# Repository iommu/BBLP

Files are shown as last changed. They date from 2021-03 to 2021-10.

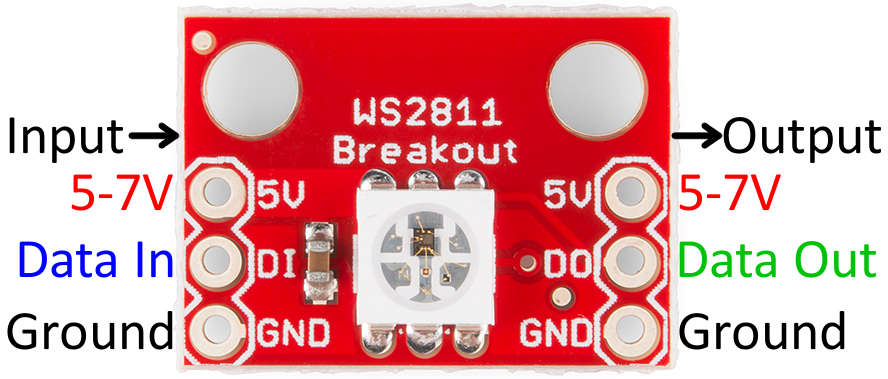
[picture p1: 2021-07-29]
Design/references/ws2812.png

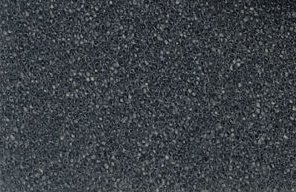
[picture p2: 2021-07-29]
Design/references/foam.jpg

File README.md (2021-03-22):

# BBLP
BreadBoard-Less Prototyper
A breadbord-less portable ECTE233 examination kit

Design files for a hardware examination kit and the associated programmer board.

## Directories
Schematics : *directory containing all schematics for the PCBs*
    - MainBoard : *schematics for the main PCB upon which everything sits*
    - IOBoard : *schematics for the small OLED I/O boards, 7 of which are mounted on the MainBoard*
    - TileBoard : *Small programmable tiles which form a stand-in for logic ICs*
    - Programmer : *A dual purpose programmer PCB with connection to the J-Link programmer, an onboard USB-TTL and a pogo pin programmer cable*
Software : *directory of all software related to the board*
    -
Design : *all design files including .stl files for 3D printing*
    -

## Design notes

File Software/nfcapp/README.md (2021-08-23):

# nfcapp

A new Flutter project.

## Getting Started

This project is a starting point for a Flutter application.

A few resources to get you started if this is your first Flutter project:

- [Lab: Write your first Flutter app](https://flutter.dev/docs/get-started/codelab)
- [Cookbook: Useful Flutter samples](https://flutter.dev/docs/cookbook)

For help getting started with Flutter, view our
[online documentation](https://flutter.dev/docs), which offers tutorials,
samples, guidance on mobile development, and a full API reference.

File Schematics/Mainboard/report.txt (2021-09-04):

Info: Front (top side) placement file: '/home/iommu/Desktop/ECTE457/BBLP/Schematics/Mainboard/output/Mainboard-top-pos.csv'.
Info: Component count: 38.
Info: Back (bottom side) placement file: '/home/iommu/Desktop/ECTE457/BBLP/Schematics/Mainboard/output/Mainboard-bottom-pos.csv'.
Info: Component count: 63.
Info: Full component count: 101.
Info: File generation successful.

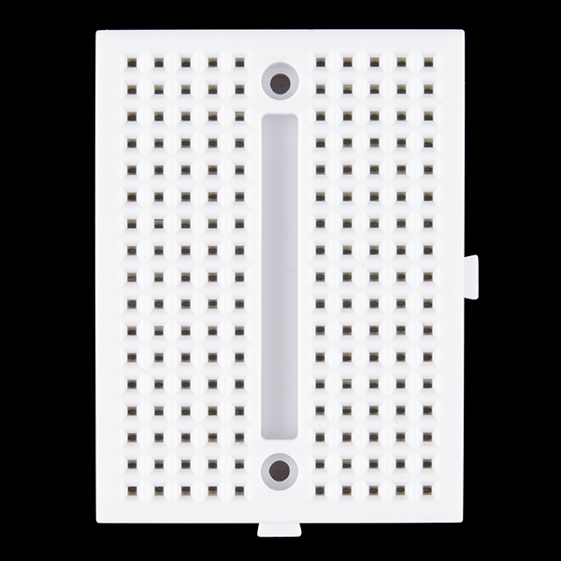
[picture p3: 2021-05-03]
Design/references/breadboard-top.jpg

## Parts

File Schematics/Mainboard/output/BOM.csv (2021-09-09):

Comment | Designator | Footprint | LCSC Part #
0u1 Unpolarized capacitor, small symbol | C1,C3,C6 | C_0603_1608Metric | C14663
10u Unpolarized capacitor, small symbol | C2,C4,C5,C9,C10 | C_0603_1608Metric | C19702
1u Unpolarized capacitor, small symbol | C7,C8 | C_0603_1608Metric | C15849
SHORT LED Light emitting diode, small symbol | D1 | LED_1206_3216Metric_Castellated | C2286
SS24 Diode, small symbol | D2 | D_SMA | C181203
Red Light emitting diode, small symbol | D3 | LED_1206_3216Metric_Castellated | C2286
FM-B2020RGBA-HG RGB LED, blue/red/green/anode | D4 | LED_BL-FL7680RGB | C108793
Gre Light emitting diode, small symbol | D5 | LED_1206_3216Metric_Castellated | C434420
Yel Light emitting diode, small symbol | D6 | LED_1206_3216Metric_Castellated | C205450
MountingHole Mounting Hole without connection | H1,H2,H3,H4 | MountingHole_3.2mm_M3
USB-C USB 2.0-only Type-C Receptacle connector | J1 | USB_C_Receptacle_HRO_TYPE-C-31-M-12 | C2835315
Pololu DC-DC Generic connector, single row, 01x04, script generated (kicad-library-utils/schlib/autogen/connector/) | J2 | PinSocket_1x04_P2.54mm_Vertical
USB Alt Generic connector, single row, 01x04, script generated (kicad-library-utils/schlib/autogen/connector/) | J3 | PinSocket_1x04_P2.54mm_Vertical
NFC Conn Generic connector, single row, 01x08, script generated (kicad-library-utils/schlib/autogen/connector/) | J4 | PinSocket_1x08_P2.54mm_Vertical
Prot in Generic connector, single row, 01x06, script generated (kicad-library-utils/schlib/autogen/connector/) | J5 | PinSocket_1x06_P2.54mm_Vertical
Prot out Generic connector, single row, 01x06, script generated (kicad-library-utils/schlib/autogen/connector/) | J6 | PinSocket_1x06_P2.54mm_Vertical
Power rail Generic connector, double row, 02x36, odd/even pin numbering scheme (row 1 odd numbers, row 2 even numbers), script generated (kicad-library-utils/schlib/autogen/connector/) | J7,J8 | PinSocket_2x36_P2.54mm_Vertical
Batt alt Generic connector, single row, 01x02, script generated (kicad-library-utils/schlib/autogen/connector/) | J9 | PinSocket_1x02_P2.54mm_Vertical
CHG in Generic connector, single row, 01x06, script generated (kicad-library-utils/schlib/autogen/connector/) | J10 | PinSocket_1x06_P2.54mm_Vertical
Batt Generic connector, single row, 01x02, script generated (kicad-library-utils/schlib/autogen/connector/) | J11 | JST_PH_S2B-PH-SM4-TB_1x02-1MP_P2.00mm_Horizontal
CHG out Generic connector, single row, 01x06, script generated (kicad-library-utils/schlib/autogen/connector/) | J12 | PinSocket_1x06_P2.54mm_Vertical
DC-DC in Generic connector, single row, 01x06, script generated (kicad-library-utils/schlib/autogen/connector/) | J13 | PinSocket_1x06_P2.54mm_Vertical
DC-DC out Generic connector, single row, 01x06, script generated (kicad-library-utils/schlib/autogen/connector/) | J14 | PinSocket_1x06_P2.54mm_Vertical
OLED Generic connector, single row, 01x04, script generated (kicad-library-utils/schlib/autogen/connector/) | J16 | PinSocket_1x04_P2.54mm_Vertical
I0 Generic connector, single row, 01x01, script generated (kicad-library-utils/schlib/autogen/connector/) | J20 | PinSocket_1x01_P2.54mm_Vertical
I1 Generic connector, single row, 01x01, script generated (kicad-library-utils/schlib/autogen/connector/) | J23 | PinSocket_1x01_P2.54mm_Vertical
I2C OLED 0 Generic connector, single row, 01x04, script generated (kicad-library-utils/schlib/autogen/connector/) | J24 | PinSocket_1x04_P2.54mm_Vertical
I2C OLED 1 Generic connector, single row, 01x04, script generated (kicad-library-utils/schlib/autogen/connector/) | J25 | PinSocket_1x04_P2.54mm_Vertical
I2C OLED 2 Generic connector, single row, 01x04, script generated (kicad-library-utils/schlib/autogen/connector/) | J26 | PinSocket_1x04_P2.54mm_Vertical
I2C OLED 3 Generic connector, single row, 01x04, script generated (kicad-library-utils/schlib/autogen/connector/) | J27 | PinSocket_1x04_P2.54mm_Vertical
I2C OLED 4 Generic connector, single row, 01x04, script generated (kicad-library-utils/schlib/autogen/connector/) | J28 | PinSocket_1x04_P2.54mm_Vertical
I2C OLED 5 Generic connector, single row, 01x04, script generated (kicad-library-utils/schlib/autogen/connector/) | J29 | PinSocket_1x04_P2.54mm_Vertical
I2C OLED 6 Generic connector, single row, 01x04, script generated (kicad-library-utils/schlib/autogen/connector/) | J30 | PinSocket_1x04_P2.54mm_Vertical
I2C OLED 7 Generic connector, single row, 01x04, script generated (kicad-library-utils/schlib/autogen/connector/) | J31 | PinSocket_1x04_P2.54mm_Vertical
I2 Generic connector, single row, 01x01, script generated (kicad-library-utils/schlib/autogen/connector/) | J32 | PinSocket_1x01_P2.54mm_Vertical
I3 Generic connector, single row, 01x01, script generated (kicad-library-utils/schlib/autogen/connector/) | J33 | PinSocket_1x01_P2.54mm_Vertical
O0 Generic connector, single row, 01x01, script generated (kicad-library-utils/schlib/autogen/connector/) | J34 | PinSocket_1x01_P2.54mm_Vertical
O1 Generic connector, single row, 01x01, script generated (kicad-library-utils/schlib/autogen/connector/) | J35 | PinSocket_1x01_P2.54mm_Vertical
O2 Generic connector, single row, 01x01, script generated (kicad-library-utils/schlib/autogen/connector/) | J36 | PinSocket_1x01_P2.54mm_Vertical
O3 Generic connector, single row, 01x01, script generated (kicad-library-utils/schlib/autogen/connector/) | J37 | PinSocket_1x01_P2.54mm_Vertical
Del in Generic connector, single row, 01x06, script generated (kicad-library-utils/schlib/autogen/connector/) | J44 | PinSocket_1x06_P2.54mm_Vertical
Del out Generic connector, single row, 01x06, script generated (kicad-library-utils/schlib/autogen/connector/) | J45 | PinSocket_1x06_P2.54mm_Vertical
3.3V Jumper Jumper, normally closed | JP1 | SolderJumper-2_P1.3mm_Open_Pad1.0x1.5mm
GND Jumper Jumper, normally closed | JP2 | SolderJumper-2_P1.3mm_Open_Pad1.0x1.5mm
Jumper Jumper, normally closed | JP3,JP4 | SolderJumper-2_P1.3mm_Open_Pad1.0x1.5mm
SHDN Jumper, normally open, small symbol | JP5 | SolderJumper-2_P1.3mm_Open_Pad1.0x1.5mm
DC_DC Jumper, normally closed | JP6 | SolderJumper-2_P1.3mm_Open_Pad1.0x1.5mm
AO3401A -4.0A Id, -30V Vds, P-Channel MOSFET, SOT-23 | Q1 | SOT-23 | C347476
DTC143T Digital NPN Transistor, 4k7/NONE, SOT-23 | Q2,Q3 | SOT-323_SC-70 | C122986
10k Resistor, small symbol | R1,R2,R3,R12,R14,R15,R18,R19,R25,R26,R27,R28 | R_0603_1608Metric | C25804
65 Resistor, small symbol | R4,R8 | R_0603_1608Metric | C23032
100k Resistor, small symbol | R5 | R_0603_1608Metric | C25803
0 Resistor, small symbol | R6,R7 | R_1206_3216Metric | C17888
15 Resistor, small symbol | R9,R10 | R_0603_1608Metric | C22810
47k Resistor, small symbol | R11,R13,R16,R17 | R_0603_1608Metric | C25819
1k5 Resistor, small symbol | R20,R21,R22 | R_0603_1608Metric | C22843
1k Resistor, small symbol | R23,R24 | R_0603_1608Metric | C21190
5k1 Resistor, small symbol | R31,R32 | R_0603_1608Metric | C23186
RESET Push button switch, generic, two pins | SW1 | SW_Push_1P1T_NO_6x6mm_H9.5mm | C778181
SW_SPDT Switch, single pole double throw | SW2 | SW-TH_SS-12D11G5 | C692484
Rot Rotary encoder, dual channel, incremental quadrate outputs, with switch | SW3,SW4 | RotaryEncoder_Alps_EC11E-Switch_Vertical_H20mm
3.3V Wire TP test point | TP1 | TestPoint_Keystone_5015_Micro-Minature
GND Wire TP test point | TP2 | TestPoint_Keystone_5015_Micro-Minature
ESP32-WROOM-32 RF Module, ESP32-D0WDQ6 SoC, Wi-Fi 802.11b/g/n, Bluetooth, BLE, 32-bit, 2.7-3.6V, onboard antenna, SMD | U1 | ESP32-WROOM-32 | C473012
TCA9548APWR Low voltage 8-channel I2C switch with reset, TSSOP-24 | U2 | TSSOP-24_4.4x7.8mm_P0.65mm | C130026
CH340B USB serial converter, UART, SOIC-16 | U3 | SOIC-16_3.9x9.9mm_P1.27mm | C81010
PCF8574TS 8 Bit Port/Expander to I2C Bus, SSOP-20 | U4 | SSOP-20_4.4x6.5mm_P0.65mm | C57790
MCP73833 | U5 | MSOP-10_3x3mm_P0.5mm | C511281

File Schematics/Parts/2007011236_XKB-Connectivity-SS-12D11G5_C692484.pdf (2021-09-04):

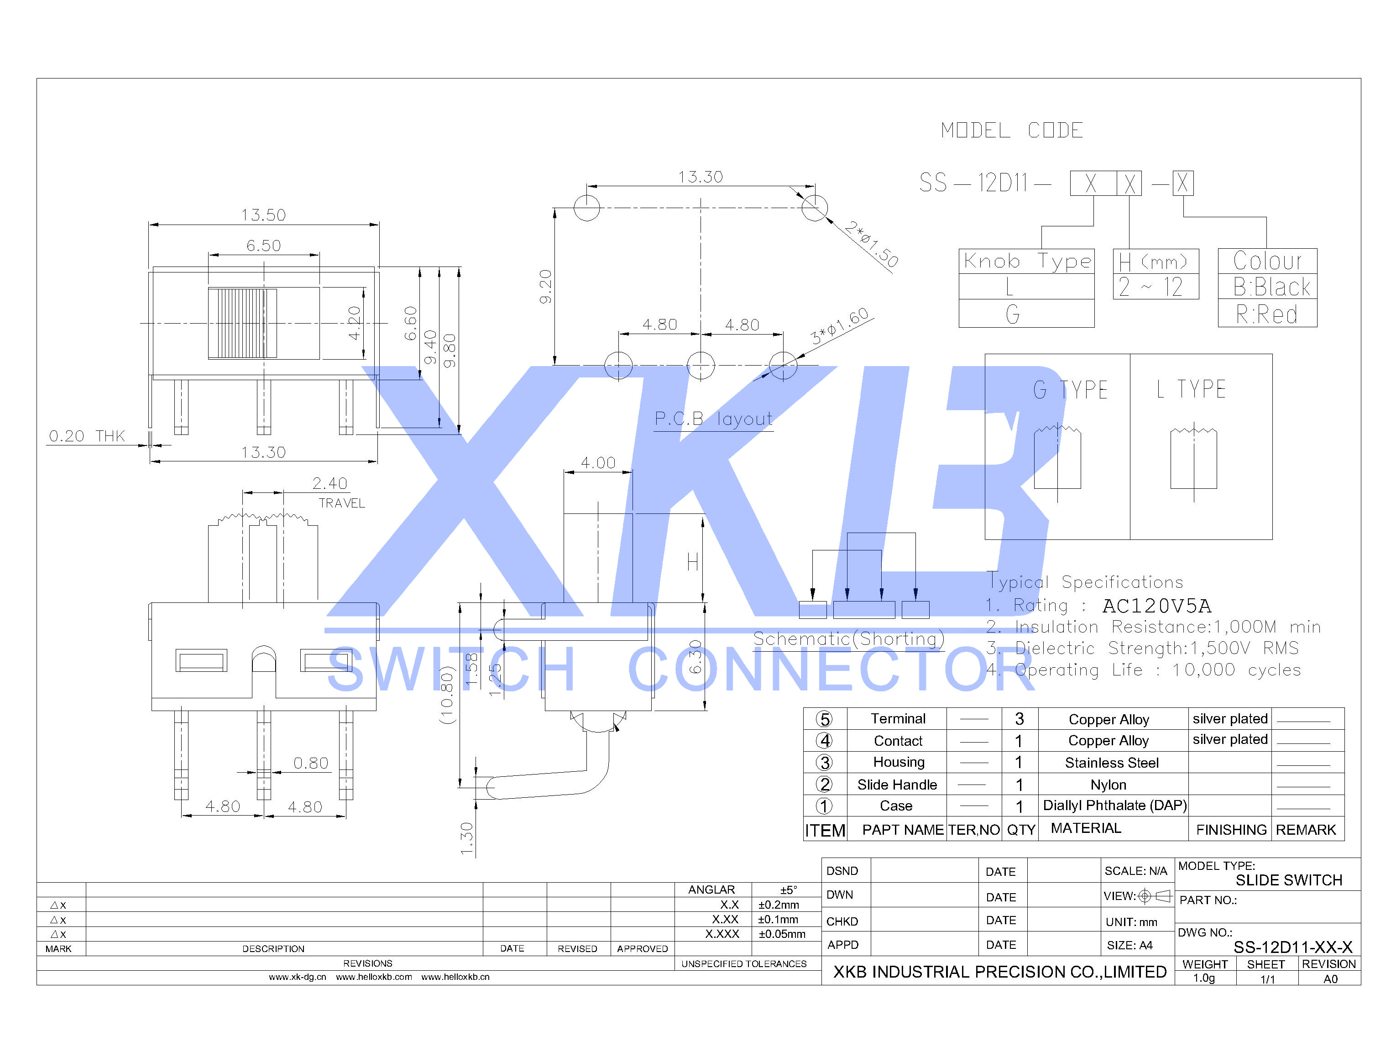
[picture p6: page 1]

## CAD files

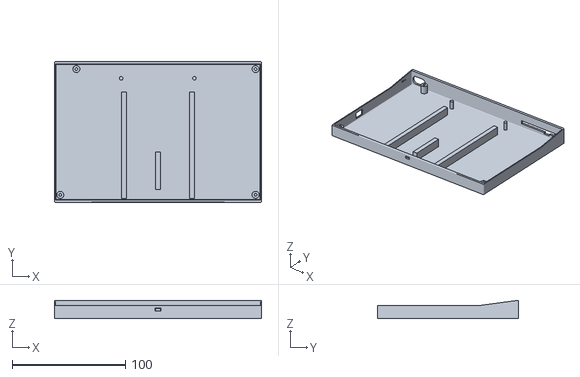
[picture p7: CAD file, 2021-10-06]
Design/print_bottom.stl
182.6 x 124.1 x 16.3

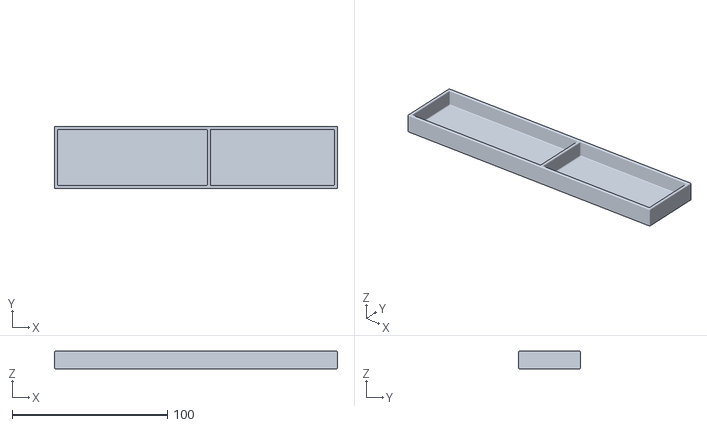
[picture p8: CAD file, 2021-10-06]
Design/print_tray.stl
182.6 x 40.0 x 11.6

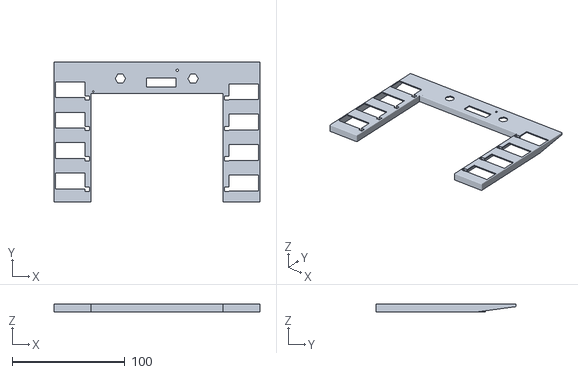
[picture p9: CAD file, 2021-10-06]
Design/print_top.stl
182.6 x 124.1 x 6.99

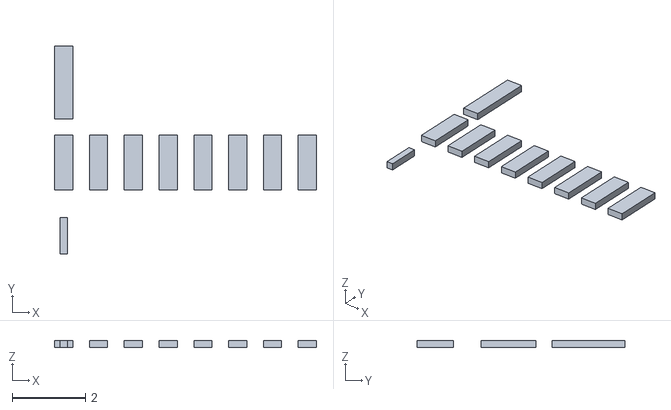
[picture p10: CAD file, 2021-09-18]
Design/oled_spaces.stl
7.15 x 5.69 x 0.2

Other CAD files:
Design/breadboard.blend
Design/mainboard.blend
Design/oled spaces.blend
Design/subboard.blend

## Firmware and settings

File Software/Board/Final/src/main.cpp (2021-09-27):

#include <Arduino.h>
#include <Wire.h>

#include "libs/interface.hpp"

void setup() {
  Serial.begin(115200); // Setup Serial for general logging

  Wire.begin(16, 17); // Setup wire 1 for Primary OLED and Pin Mux

  Wire1.begin(21, 22); // Setup wire 0 for MUX OLEDs

  Interface(); // Start primary interface
}

void loop() {}

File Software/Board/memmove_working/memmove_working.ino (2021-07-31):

/**************************************************************************
 This is an example for our Monochrome OLEDs based on SSD1306 drivers

 Pick one up today in the adafruit shop!
 ------> http://www.adafruit.com/category/63_98

 This example is for a 128x64 pixel display using I2C to communicate
 3 pins are required to interface (two I2C and one reset).

 Adafruit invests time and resources providing this open
 source code, please support Adafruit and open-source
 hardware by purchasing products from Adafruit!

 Written by Limor Fried/Ladyada for Adafruit Industries,
 with contributions from the open source community.
 BSD license, check license.txt for more information
 All text above, and the splash screen below must be
 included in any redistribution.
 **************************************************************************/

#include <Adafruit_GFX.h>
#include <Adafruit_SSD1306.h>
#include <SPI.h>
#include <Wire.h>

#define SCREEN_WIDTH 128 // OLED display width, in pixels
#define SCREEN_HEIGHT 64 // OLED display height, in pixels

// Declaration for an SSD1306 display connected to I2C (SDA, SCL pins)
// The pins for I2C are defined by the Wire-library.
// On an arduino UNO:       A4(SDA), A5(SCL)
// On an arduino MEGA 2560: 20(SDA), 21(SCL)
// On an arduino LEONARDO:   2(SDA),  3(SCL), ...
#define OLED_RESET 4 // Reset pin # (or -1 if sharing Arduino reset pin)
#define SCREEN_ADDRESS                                                         \
  0x3C ///< See datasheet for Address; 0x3D for 128x64, 0x3C for 128x32
Adafruit_SSD1306 display(SCREEN_WIDTH, SCREEN_HEIGHT, &Wire, OLED_RESET, 800000,
                         400000);

#define NUMFLAKES 10 // Number of snowflakes in the animation example

void setup() {
  Serial.begin(115200);
  Wire.begin();
  // SSD1306_SWITCHCAPVCC = generate display voltage from 3.3V internally
  if (!display.begin(SSD1306_SWITCHCAPVCC, SCREEN_ADDRESS)) {
    Serial.println(F("SSD1306 allocation failed"));
    for (;;)
      ; // Don't proceed, loop forever
  }

  // Show initial display buffer contents on the screen --
  // the library initializes this with an Adafruit splash screen.
  display.display();
  delay(2000); // Pause for 2 seconds

  // Clear the buffer
  display.clearDisplay();

  // Draw a single pixel in white
  display.drawPixel(10, 10, SSD1306_WHITE);

  // Show the display buffer on the screen. You MUST call display() after
  // drawing commands to make them visible on screen!
  display.display();
  delay(2000);
  // display.display() is NOT necessary after every single drawing command,
  // unless that's what you want...rather, you can batch up a bunch of
  // drawing operations and then update the screen all at once by calling
  // display.display(). These examples demonstrate both approaches...

  testfillrect(); // Draw rectangles (filled)
}

long curr_time;

void loop() {
  curr_time = millis();
  for (int page = 0; page < SCREEN_HEIGHT / 8; page++) {
    memmove(display.getBuffer() + page * SCREEN_WIDTH,
            display.getBuffer() + page * SCREEN_WIDTH + 1, SCREEN_WIDTH - 1);
  }
  display.display();
  Serial.println(millis() - curr_time);
}

void testfillrect(void) {
  display.clearDisplay();

  for (int16_t i = 0; i < display.height() / 2; i += 3) {
    // The INVERSE color is used so rectangles alternate white/black
    display.fillRect(i, i, display.width() - i * 2, display.height() - i * 2,
                     SSD1306_INVERSE);
    display.display(); // Update screen with each newly-drawn rectangle
    delay(1);
  }

  delay(2000);
}

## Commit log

2021-03-22 Updated gitignore for KiCad *6*
2021-03-22 Uploaded initial KiCad work
    [IOBoard.kicad_pcb, IOBoard.kicad_sch, MainBoard.kicad_pcb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]
2021-03-22 Updated subboard name
    [IOBoardConnectors.kicad_sch]
2021-03-24 IOBoard completed
    [IOBoard.kicad_pcb, IOBoard.kicad_sch]
2021-03-24 Programmer completed
    [Programmer.kicad_pcb, Programmer.kicad_sch]
2021-03-24 TileBoard completed
    [TileBoard.kicad_pcb, TileBoard.kicad_sch]
2021-05-03 Finished circuit - pre mousebites
    [IOBoard.kicad_pcb, IOBoard.kicad_sch, IOBoardConnectors.kicad_sch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]
2021-07-25 added 5x5 usb-ttl board
    [USB-TTL-CmtUser.gbr, USB-TTL-CuBottom.gbr, USB-TTL-CuTop.gbr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]
2021-07-25 added 5x5 dc-dc board
    [DC_DC-CmtUser.gbr, DC_DC-CuBottom.gbr, DC_DC-CuTop.gbr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]
2021-07-25 Added schematic + PCB for rot enc
    [Rotary Encoder.kicad_pcb, Rotary Encoder.kicad_sch]
2021-07-25 Moved F.Fab
    [Rotary Encoder.kicad_pcb]
2021-07-25 Added files for rotary encoder prod
    [Rotary Encoder-CmtUser.gbr, Rotary Encoder-CuBottom.gbr, Rotary Encoder-CuTop.gbr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]
2021-07-25 added bom
    [Rotary Encoder.csv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]
2021-07-27 USB-TTL 2cm
    [USB-TTL.kicad_pcb, USB-TTL.kicad_sch]
2021-07-27 DC-DC 2cm
    [DC-DC.kicad_pcb, DC-DC.kicad_sch]
2021-07-27 Battery charger 2cm
    [Battery charger.kicad_pcb, Battery charger.kicad_sch]
2021-07-27 rotated export pins
    [Rotary Encoder.kicad_pcb]
2021-07-29 removed schematic ref component
2021-07-29 Added blend files from first section of thesis
    [breadboard.blend, mainboard.blend, subboard.blend]
2021-07-29 Changed file structure
    [IOBoard.kicad_pcb, IOBoard.kicad_sch, IOBoardConnectors.kicad_sch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]
2021-07-31 moved DC_DC to DC-DC
    [DC_DC-CmtUser.gbr, DC_DC-CuBottom.gbr, DC_DC-CuTop.gbr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]
2021-07-31 Added defunct subcircuit project
    superseded by modular mainboard
    [SubCircuits.csv, SubCircuits.kicad_pcb, SubCircuits.kicad_sch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]
2021-07-31 Added defunct submodule
    Superseded by onboard oleds/ I/O pins
    [subModule.csv, subModule.kicad_pcb, subModule.kicad_sch]
2021-07-31 removed spi code
2021-07-31 removed tca driver
2021-08-02 Removed programmer module
    [Programmer.kicad_pcb, Programmer.kicad_sch]
2021-08-02 removed submodule and subcircuit schematics
    [SubCircuits.csv, SubCircuits.kicad_pcb, SubCircuits.kicad_sch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]
2021-08-02 Added prelim wiretester module
    [Wire tester.kicad_pcb, Wire tester.kicad_sch]
2021-08-02 Added prelim mainboard
    [Mainboard.kicad_pcb, Mainboard.kicad_sch, Power management.kicad_sch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]
2021-08-02 Added DC-DC gerbers
    [DC-DC-CmtUser.gbr, DC-DC-CuBottom.gbr, DC-DC-CuTop.gbr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]
2021-08-02 realigned pad
    [DC-DC-CmtUser.gbr, DC-DC-CuBottom.gbr, DC-DC-CuTop.gbr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]
2021-08-02 Added gerbers for batt charger
    [Battery charger-CmtUser.gbr, Battery charger-CuBottom.gbr, Battery charger-CuTop.gbr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]
2021-08-02 removed old gerbers
    [USB-TTL-CmtUser.gbr, USB-TTL-CuBottom.gbr, USB-TTL-CuTop.gbr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]
2021-08-02 Added USB-TTL gerbers
    [USB-TTL-CmtUser.gbr, USB-TTL-CuBottom.gbr, USB-TTL-CuTop.gbr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]
2021-08-06 Added gerbers for printing
    [Battery charger-CmtUser.gbr, Battery charger-CuBottom.gbr, Battery charger-CuTop.gbr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]
2021-08-06 Added stencil
    [Stencil-CmtUser.gbr, Stencil-CuBottom.gbr, Stencil-CuTop.gbr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]
2021-09-04 Added Mainboard rev 1.0
    [BOM.csv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]
2021-09-04 Updated I2C power
    [Mainboard.kicad_pcb, Mainboard.kicad_sch, User interface.kicad_sch]
2021-09-09 Final print version mainboard
    [BOM.csv, Mainboard.kicad_pcb, Mainboard.kicad_sch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]
2021-09-09 New kicad version
    [Mainboard.kicad_pcb]
2021-09-09 added parts files for spare parts
    [parts.kicad_sch]
2021-09-09 removed parts file
    [parts.kicad_sch]
2021-09-09 added prelim wire tester
    [Wire tester.kicad_pcb, Wire tester.kicad_sch]
2021-09-18 Added spacer file
    [oled spaces.blend, oled_spaces.stl]
2021-09-19 Added ESP32 encoder lib from ...
    https://github.com/madhephaestus/ESP32Encoder/
2021-09-19 Added base funcs + LED func
2021-09-19 Added encoder test
2021-09-19 Final mainboard design
    [mainboard.blend]
2021-09-22 rev 1 top print
2021-09-22 Added LED test arduino sketch
2021-09-22 Added final Mainboard render
    [mainboard.blend]
2021-09-22 Threading and waveform display
2021-09-23 Fixed I2C overlapp and started bit recording
    [main.cpp]
2021-09-27 Added i2c mutex lock
2021-09-27 Working JSON and selective drawing
    Note, too many issues with pure OOP so calling from intermediary function best way
    [main.cpp]
2021-09-28 second top print
2021-09-30 Modified OLED holes and switch hole for better fit
2021-10-06 Fixed indicator LED issue
2021-10-06 Added proper text to wire tester board
    [Wire tester.kicad_sch]
2021-10-06 Added small wire/ chip tray
2021-10-06 Added printable STL files
    [print_bottom.stl, print_top.stl, print_tray.stl]
